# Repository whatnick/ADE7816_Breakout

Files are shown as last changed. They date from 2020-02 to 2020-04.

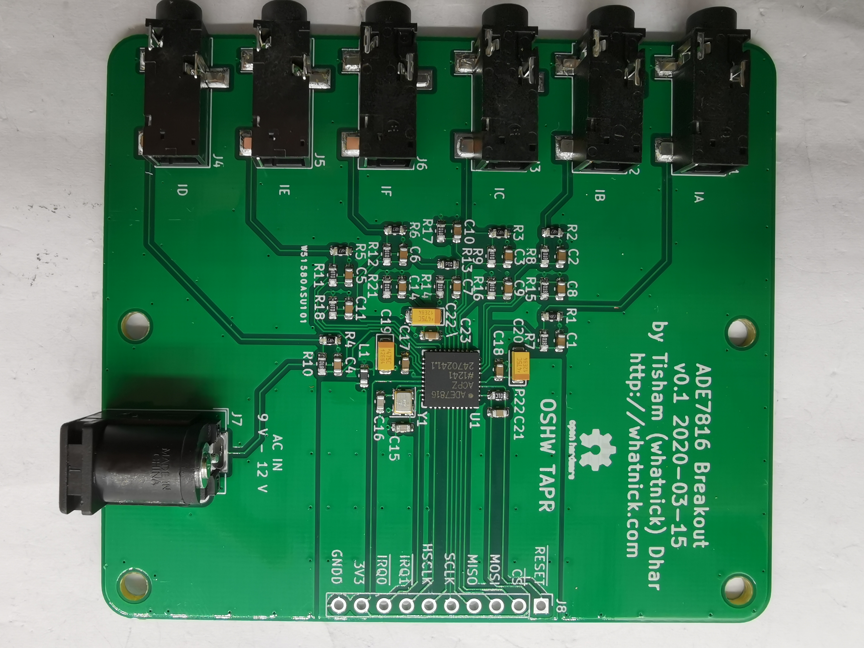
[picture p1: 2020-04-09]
doc/assembled_front.jpg

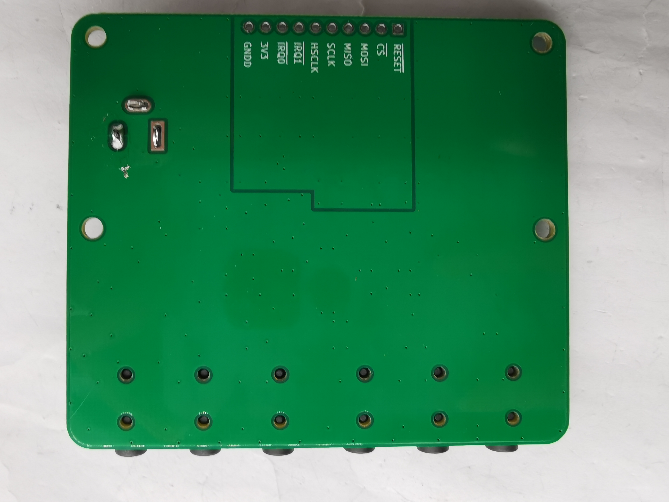
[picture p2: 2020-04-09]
doc/assembled_back.jpg

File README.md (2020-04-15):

# Breakout Board for ADE7816 6-Channel Energy Monitor ASIC

For those wanting to monitor lots of individual channels in a single-phase household the
[ADE7816](https://www.analog.com/en/products/ade7816.html)
is an ideal solution. It allows differential current sensors for 3 channels and single ended current
sensors for 3 more channels. The MCU interface is over SPI or I2C bus, and Arduino driver will
be developed along with this breakout board.

## Supporting Software

There is work in progress on supporting this board in [Arduino](https://github.com/whatnick/ADE7816_Arduino) and [Micropython](https://github.com/whatnick/ade7816_micropython).

## Getting the hardware

The hardware can be obtained as PCB, PCB + Parts Kit or Fully assembled.

- [Tindie Fully assembled](https://www.tindie.com/stores/whatnick/)
- [Aisler partkit](https://aisler.net/whatnick/playground/ade7816-breakout)
- [OSHPark PCB](https://oshpark.com/shared_projects/oovHySXk)
- [PCBWay PCB](https://www.pcbway.com/project/shareproject/Breakout_Board_for_ADE7816_6_Channel_Energy_Monitor_ASIC.html)

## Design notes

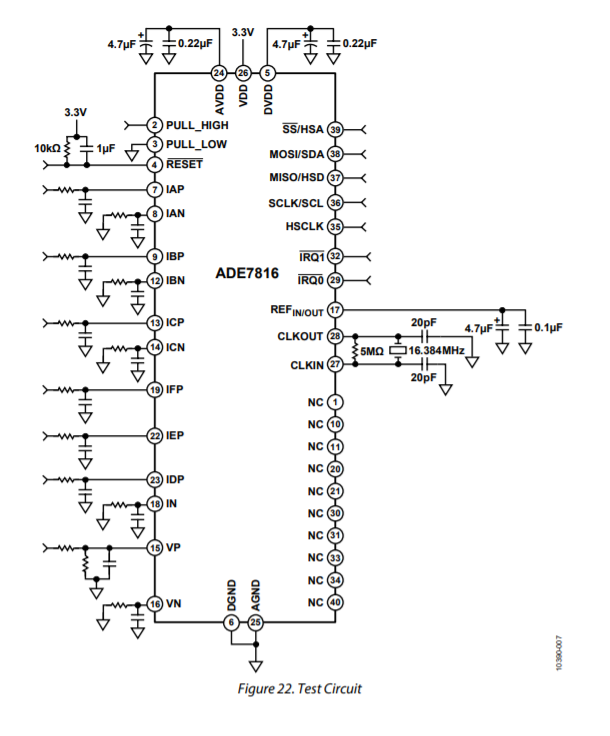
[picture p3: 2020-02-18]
doc/reference_schematic.PNG

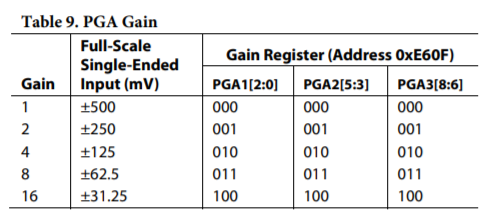
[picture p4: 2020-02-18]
doc/input_range_gain.PNG

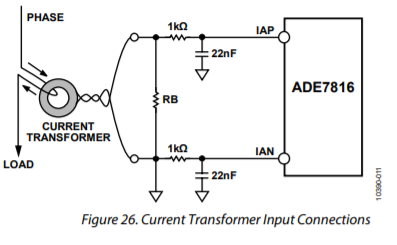
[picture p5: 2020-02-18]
doc/ct_antialias_filter.PNG

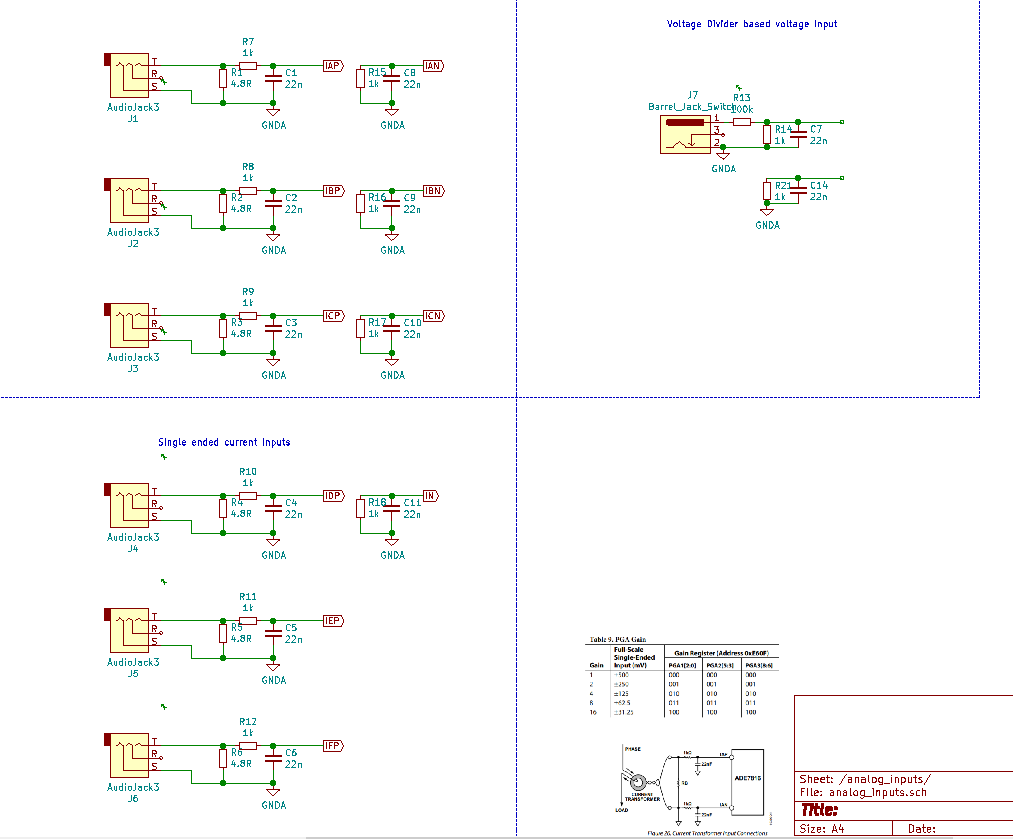
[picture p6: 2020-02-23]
doc/input_rc_network.PNG

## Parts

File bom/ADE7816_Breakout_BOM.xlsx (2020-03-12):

References | manf# | Value | Footprint | Quantity
C1, C2, C3, C4, C5, C6, C7, C8, C9, C10, C11, C14 | GCE188R71H223KA01D | 22n | C_0603_1608Metric | 12
C15, C16 | GCM1885C2A200JA16D | 20p | C_0603_1608Metric | 2
C17, C18, C23 | GCM188R71E224KA55D | 220n | C_0603_1608Metric | 3
C21 | GRT188C8YA105KE13D | 1u | C_0603_1608Metric | 1
C19, C20, C22 | TAJA475K016UNJ | 4.7u | CP_EIA-3216-18_Kemet-A | 3
R1, R2, R3, R4, R5, R6 | CRL0603-FW-4R70ELF | 4.7R | R_0603_1608Metric | 6
R13 | RT0603FRE10100KL | 100k | R_0603_1608Metric_Pad1.05x0.95mm_HandSolder | 1
R7, R8, R9, R10, R11, R12, R14, R15, R16, R17, R18, R21 | RT0603FRE101KL | 1k | R_0603_1608Metric | 12
R22 | RT0603FRE1310KL | 10k | R_0603_1608Metric | 1
L1 | BLM18KG300TN1D | Ferrite | L_0603_1608Metric | 1
U1 | ADE7816ACPZ | ADE7816ACPZ | QFN-40-1EP_5x5mm_P0.4mm_EP3.6x3.6mm_ThermalVias | 1
Y1 | ABM10-16.384MHZ-D30-T3 | 16.384MHz | Crystal_SMD_2520-4Pin_2.5x2.0mm | 1
J7 | PJ-002A | Barrel_Jack_Switch | BarrelJack_Horizontal | 1
J1, J2, J3, J4, J5, J6 | SJ-3523-SMT-TR | AudioJack3 | Jack_3.5mm_CUI_SJ-3523-SMT_Horizontal | 6

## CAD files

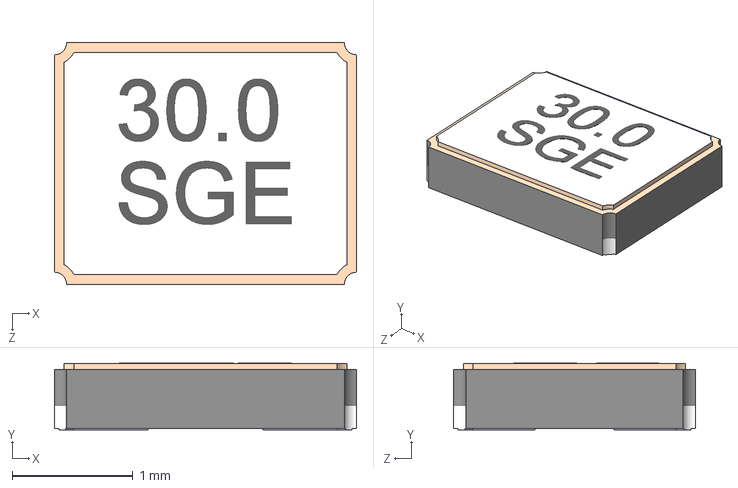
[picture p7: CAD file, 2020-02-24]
3dmodels/SW3dPS-CRY_2520.STEP
2.50 x 0.552 x 2.00 mm

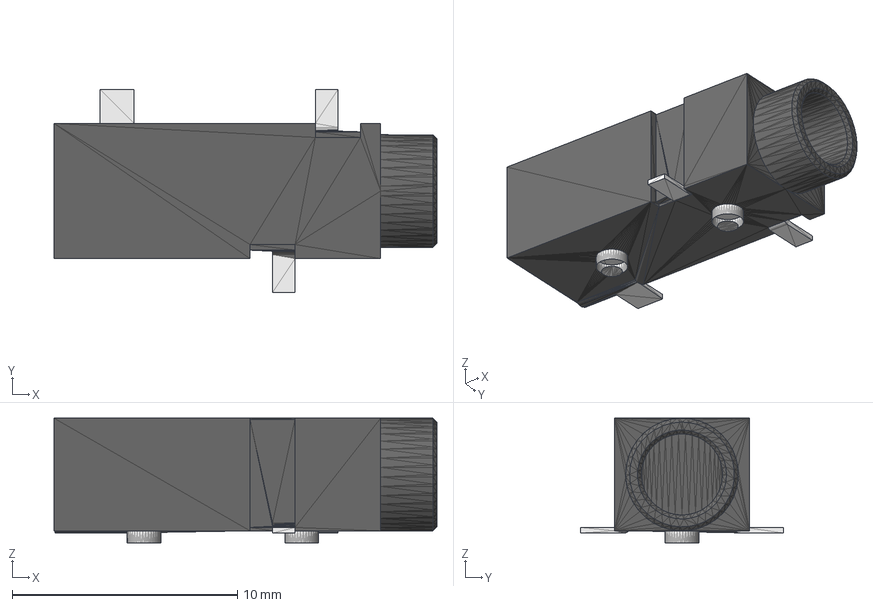
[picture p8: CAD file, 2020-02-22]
3dmodels/CUI_SJ-3523.step
17.0 x 9.00 x 5.80 mm

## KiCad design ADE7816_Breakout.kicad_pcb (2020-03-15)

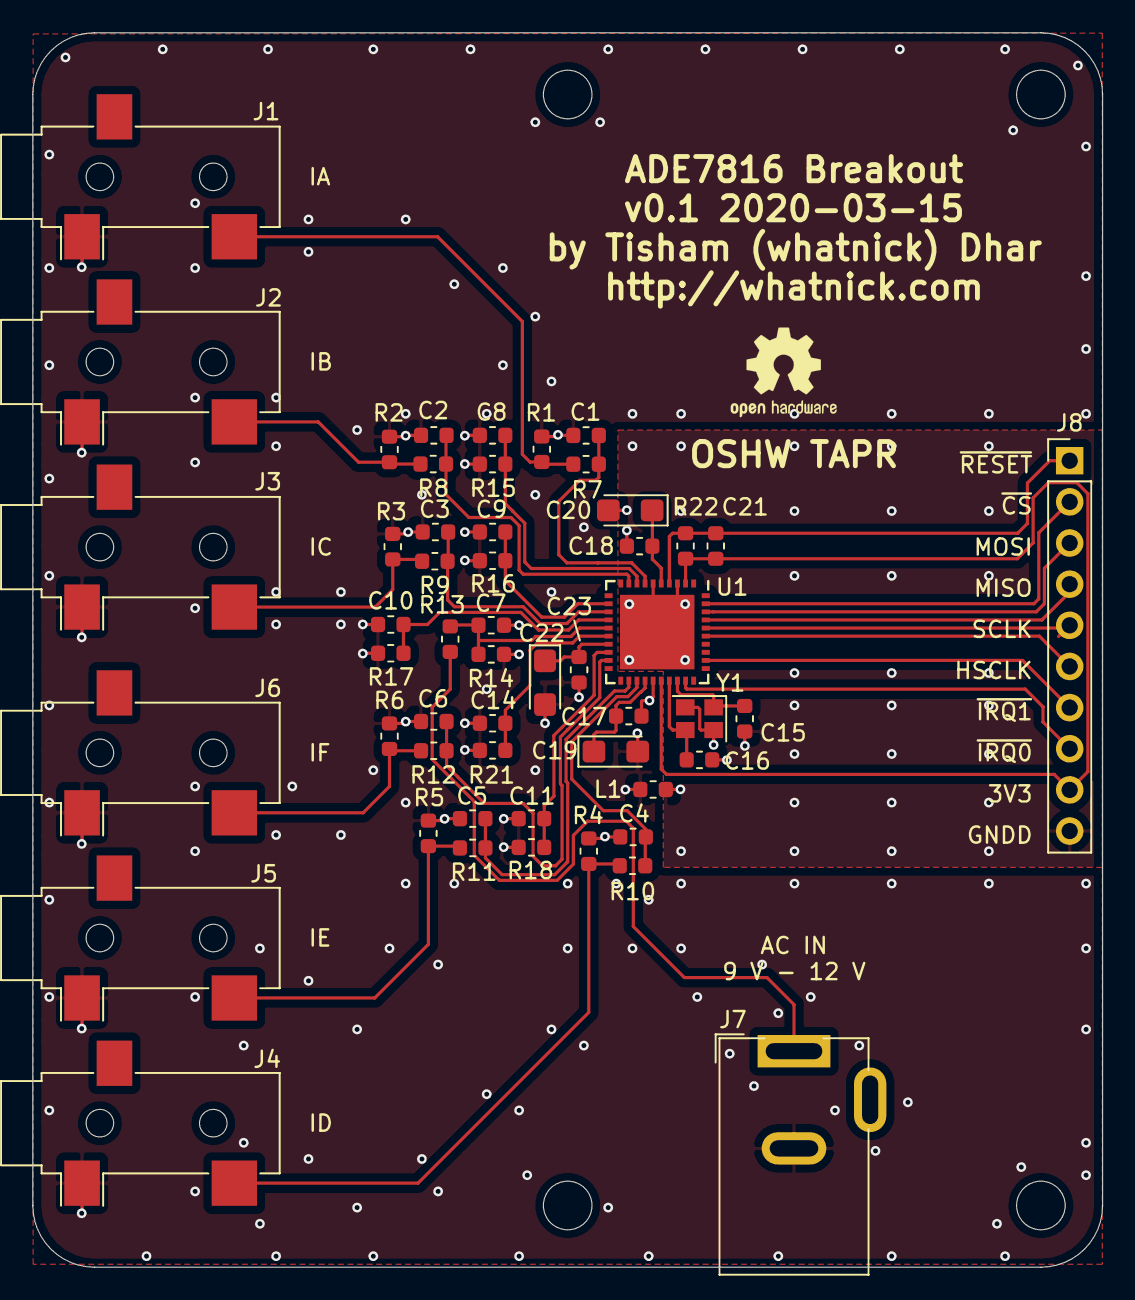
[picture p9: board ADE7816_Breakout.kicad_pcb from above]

Board: 2 copper layers, 66.0 x 76.2 mm, 57 parts (0 on the bottom side), 35 nets.

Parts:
C1, C2, C3, C4, C5, C6, C7, C8, C9, C10, C11, C14: 22n; C_0603_1608Metric
C15, C16: 20p; C_0603_1608Metric
C17, C18, C23: 220n; C_0603_1608Metric
C19, C20, C22: 4.7u; CP_EIA-3216-18_Kemet-A
C21: 1u; C_0603_1608Metric
H1, H2, H3, H4: MountingHole; MountingHole_3mm
J1, J2, J3, J4, J5, J6: AudioJack3; Jack_3.5mm_CUI_SJ-3523-SMT_Horizontal
J7: Barrel_Jack_Switch; Barrel_Jack_CUI_PJ-002A
J8: Conn_01x10; PinHeader_1x10_P2.54mm_Vertical
L1: Ferrite; L_0603_1608Metric
LOGO1: Logo_Open_Hardware_Small; OSHW-Logo2_7.3x6mm_SilkScreen
R1, R2, R3, R4, R5, R6: 4.7R; R_0603_1608Metric
R7, R8, R9, R10, R11, R12, R14, R15, R16, R17, R18, R21: 1k; R_0603_1608Metric
R13: 100k; R_0603_1608Metric
R22: 10k; R_0603_1608Metric
U1: ADE7816ACPZ; QFN-40-1EP_6x6mm_Pitch0.5mm
Y1: 16.384MHz; Crystal_SMD_2520-4Pin_2.5x2.0mm

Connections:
+3V3: C21.1, J8.9, R22.1, U1.2, U1.26
/analog_inputs/IA: J1.2, R1.2, R7.2
/analog_inputs/IB: J2.2, R2.2, R8.2
/analog_inputs/IC: J3.2, R3.2, R9.2
/analog_inputs/ID: J4.2, R4.2, R10.2
/analog_inputs/IE: J5.2, R5.2, R11.2
/analog_inputs/IF: J6.2, R6.2, R12.2
/meter_module/AVDD: C17.1, C19.1, U1.24
/meter_module/CLKIN: C16.2, U1.27, Y1.3
/meter_module/CLKOUT: C15.2, U1.28, Y1.1
/meter_module/DVDD: C18.1, C20.1, U1.5
/meter_module/HSCLK: J8.6, U1.35
/meter_module/MISO: J8.4, U1.37
/meter_module/MOSI: J8.3, U1.38
/meter_module/SCLK: J8.5, U1.36
/meter_module/~CS: J8.2, U1.39
/meter_module/~IRQ0: J8.8, U1.29
/meter_module/~IRQ1: J8.7, U1.32
/meter_module/~RESET: C21.2, J8.1, R22.2, U1.4
GNDA: C1.2, C2.2, C3.2, C4.2, C5.2, C6.2, C7.2, C8.2, C9.2, C10.2, C11.2, C14.2, C17.2, C19.2, C22.2, C23.2, J1.1, J2.1, J3.1, J4.1, J5.1, J6.1, J7.2, L1.1, R1.1, R2.1, R3.1, R4.1, R5.1, R6.1, R14.2, R15.1, R16.1, R17.1, R18.1, R21.2, U1.25
GNDD: C15.1, C16.1, C18.2, C20.2, J8.10, L1.2, U1.3, U1.6, U1.41, Y1.2, Y1.4
IAN: C8.1, R15.2, U1.8
IAP: C1.1, R7.1, U1.7
IBN: C9.1, R16.2, U1.12
IBP: C2.1, R8.1, U1.9
ICN: C10.1, R17.2, U1.14
ICP: C3.1, R9.1, U1.13
IDP: C4.1, R10.1, U1.23
IEP: C5.1, R11.1, U1.22
IFP: C6.1, R12.1, U1.19
IN: C11.1, R18.2, U1.18
unnamed: C22.1, C23.1, U1.17
unnamed: J7.1, R13.2
VN: C14.1, R21.1, U1.16
VP: C7.1, R13.1, R14.1, U1.15

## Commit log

2020-02-17 Initial import
    [ADE7816_Breakout.kicad_pcb, ADE7816_Breakout.sch]
2020-02-18 Add doc snippets and extra sheets
    [ADE7816_Breakout.sch, analog_inputs.sch, meter_module.sch]
2020-02-21 Start adding analog inputs and filters
    [ADE7816_Breakout.kicad_pcb, analog_inputs.sch, meter_module.sch]
2020-02-21 Add crystal load caps
    [ADE7816_Breakout.kicad_pcb, analog_inputs.sch, meter_module.sch]
2020-02-22 Add more parts and placements
    [ADE7816_Breakout.kicad_pcb, CUI_SJ-3523.step, analog_inputs.sch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]
2020-02-23 Initial round of schematic parts
    [ADE7816_Breakout.kicad_pcb, analog_inputs.sch, meter_module.sch]
2020-02-23 Add part numbers and begin placement
    [ADE7816_Breakout.kicad_pcb, analog_inputs.sch, meter_module.sch]
2020-02-24 make ridiculously thin traces for route attempt
    [ADE7816_Breakout.kicad_pcb, ADE7816_Breakout.sch, SW3dPS-CRY_2520.STEP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]
2020-02-27 Some routing
    [ADE7816_Breakout.kicad_pcb]
2020-02-28 Violate DRC and get some routing done
    [ADE7816_Breakout.kicad_pcb]
2020-02-29 Get some sort of 100% routing with DRC broken
    [ADE7816_Breakout.kicad_pcb]
2020-02-29 Output Gerbers
    [ADE7816_Breakout-B_Cu.gbr, ADE7816_Breakout-B_Mask.gbr, ADE7816_Breakout-B_Paste.gbr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]
2020-02-29 Add stitching vias
    [ADE7816_Breakout.kicad_pcb]
2020-02-29 Regen gerbers
    [ADE7816_Breakout-B_Cu.gbr, ADE7816_Breakout-B_Mask.gbr, ADE7816_Breakout-B_Paste.gbr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]
2020-02-29 Update BOM
2020-03-11 Modified the library symbols used for the stereo jack and DC jack. Made stereo jack footprint reference local copy in folder lib/misc.pretty to avoid compatibility issues between different versions o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
    [ADE7816_Breakout.kicad_pcb, analog_inputs.sch, meter_module.sch]
2020-03-12 - Updated U1 to use QFN40 6x6mm 0.5 pitch on both schematic and PCB and updated the layout to accomidate this. - moved all footprint files to the modules directory - created modified footprint for th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
    [ADE7816_Breakout.kicad_pcb, analog_inputs.sch, meter_module.sch]
2020-03-15 Add silk screen details
    [ADE7816_Breakout.kicad_pcb, ADE7816_Breakout.sch]
2020-03-15 Label nets for currents
    [ADE7816_Breakout.kicad_pcb, analog_inputs.sch]
2020-03-15 Add more silk screen
    [ADE7816_Breakout.kicad_pcb]
2020-03-16 New Gerbers
    [ADE7816_Breakout-B_Cu.gbr, ADE7816_Breakout-B_Mask.gbr, ADE7816_Breakout-B_Paste.gbr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]
2020-03-16 Add placement file
    [ADE7816_Breakout-all-pos.csv]
2020-04-09 Added assembled board photos
